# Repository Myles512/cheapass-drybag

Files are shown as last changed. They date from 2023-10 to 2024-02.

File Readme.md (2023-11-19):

# Cheapass Filament Drybag
Store filament in and print from a zipper bag. Inspired by [churls Filament Spool Drybox and Feeder](https://github.com/churls5495/Filament_Spool_Drybox).

Cereal boxes are a great idea for filament storage, but I am cheap and have way too many opened spools of filament. In theory you can place a properly dried spool into a zipper bag and never have to open it again. It should stay dry (hopefully under 10% humidity thanks to the desiccant) until you've expended the entire spool.

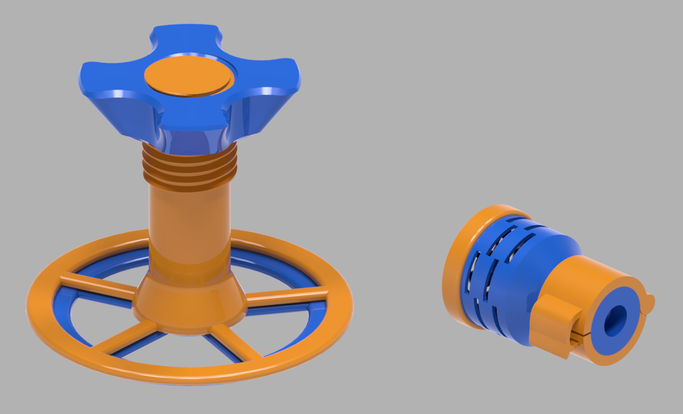
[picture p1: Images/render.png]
Render of the cheapass drybag


* Screw a [PC4-M10 bowden coupler](https://www.3dlabtech.ca/product/pneumatic-bowden-coupler-pc4-m10/) or [PC4-M6 bowden coupler](https://www.3dlabtech.ca/product/pneumatic-bowden-coupler-pc4-m6/) into the top of the guide.
* Insert a short length of 4mm OD ptfe tubing through the coupler and desiccant storage chamber.
* Attach turntable top and bottom with a [608 skateboard bearing](https://www.3dlabtech.ca/product/s608zz-bearing-abec-7-pack-of-10/).
* Load some desiccant or molecular sieve into the storage chamber and screw the lid on.
* Cut a small hole in the corner of a zipper bag, a little smaller than the ridged part of the guide.
* Insert the ridged side of the guide through the hole in the bag.
* Remove the built in support from the clamp and then clamp it around the bag and guide.
* Feed properly dried filament through the tube from the inside of the bag.
* Put the filament in the bag and seal it. Ensure the bag has enough air in it that the spool can spin freely.
* Place the bag on its side with the spool sitting on the turntable.
* Feed the filament into your printer and print!

Update: I've added a version with a spool guide as I found spools that have cutouts in the walls (most spools) had a tendency to catch on the desiccant chamber when a sufficient amount of filament had been used.

The bagged spools should fit fairly well into most existing filament storage (eg. reprack), and seem to sit nicely on top of enclosed printers as long as the top panel doesn't melt the bag.
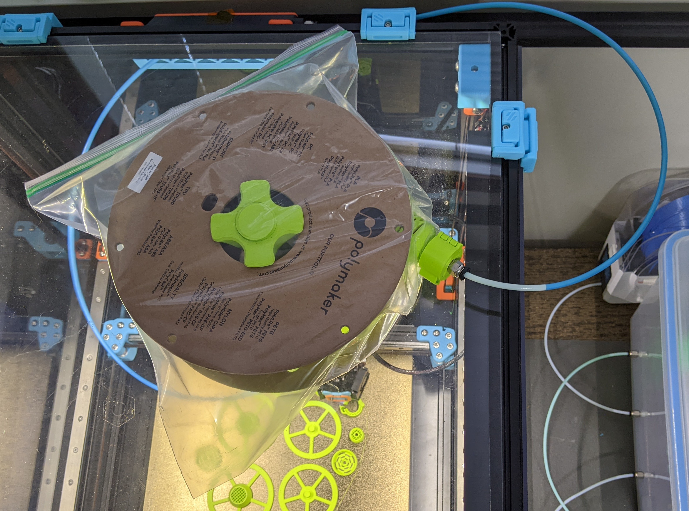
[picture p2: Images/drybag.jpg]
drybag sitting on top of a printer


If you have any comments/suggestions you can [contact me on discord](https://discord.com/users/mjlo).

gif of filament being pulled out of a drybag

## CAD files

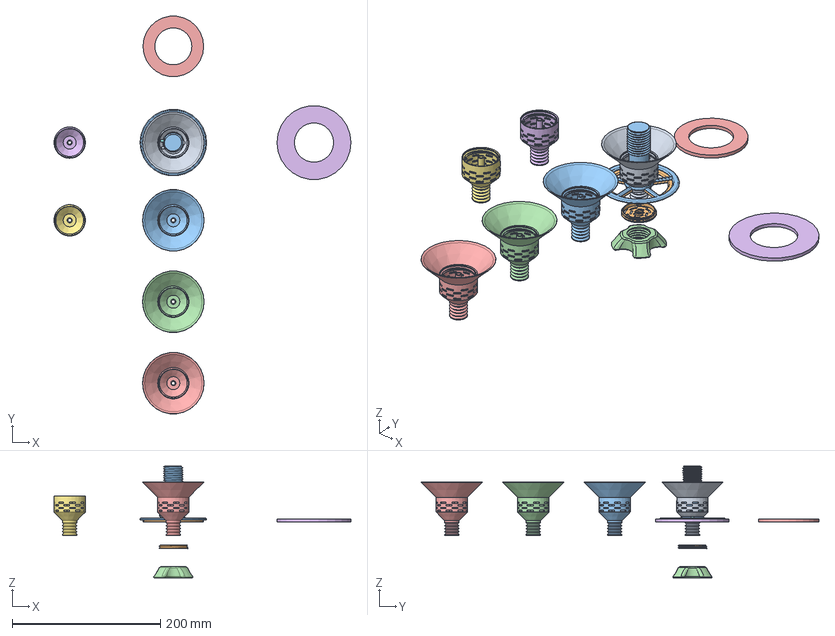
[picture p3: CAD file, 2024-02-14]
CAD/Cheapass Filament Storage Drybags.step
401.2 x 537.0 x 150.8 mm
Tube holder with desiccant storage
Bag Clamp
Turntable
Spool Big Hole Washer

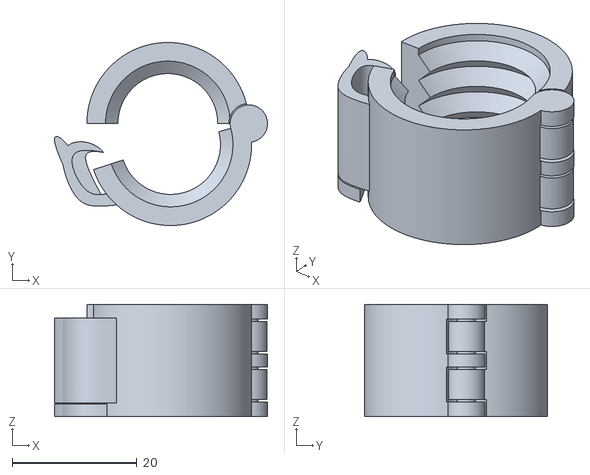
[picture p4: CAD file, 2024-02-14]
STL/Bag Clamp - Slightly Longer Tooth.stl
34.2 x 29.4 x 18.0

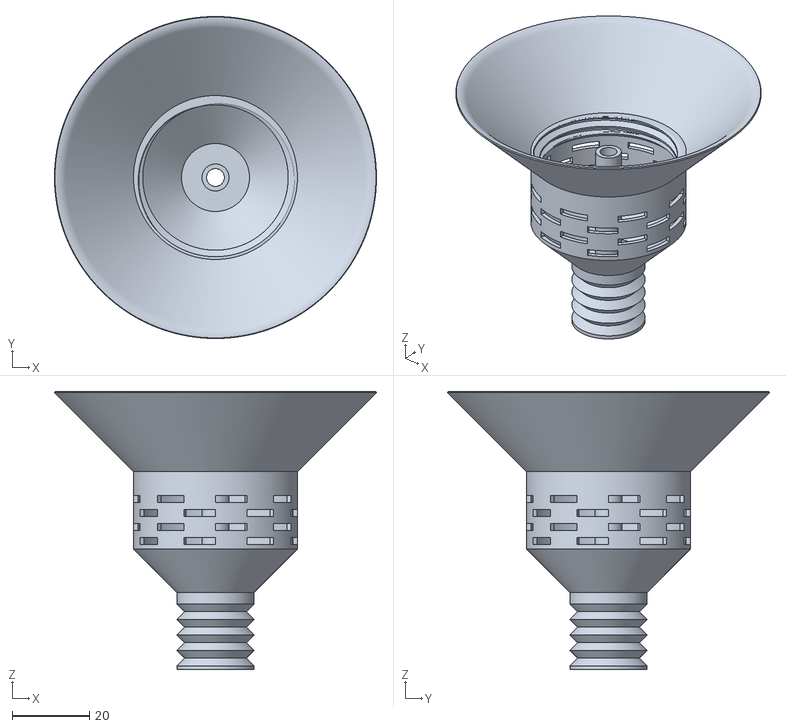
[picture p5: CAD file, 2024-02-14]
STL/Bowden Guide and Desiccant Storage with Spool Guide - Cheap Collet.stl
83.3 x 83.3 x 72.0

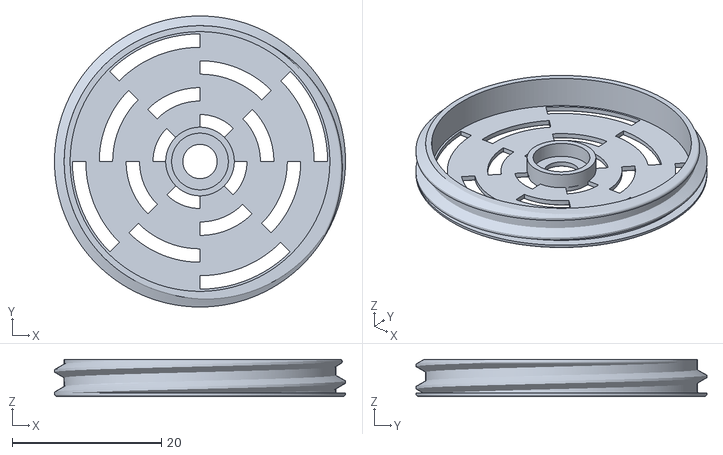
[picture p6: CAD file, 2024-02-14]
STL/Desiccant Lid.stl
39.0 x 39.0 x 5.00

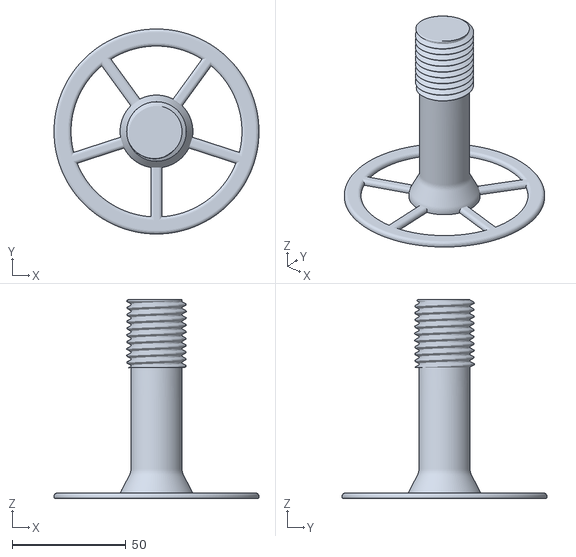
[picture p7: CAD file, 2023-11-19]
STL/Turntable 85mm.stl
90.0 x 90.0 x 87.5

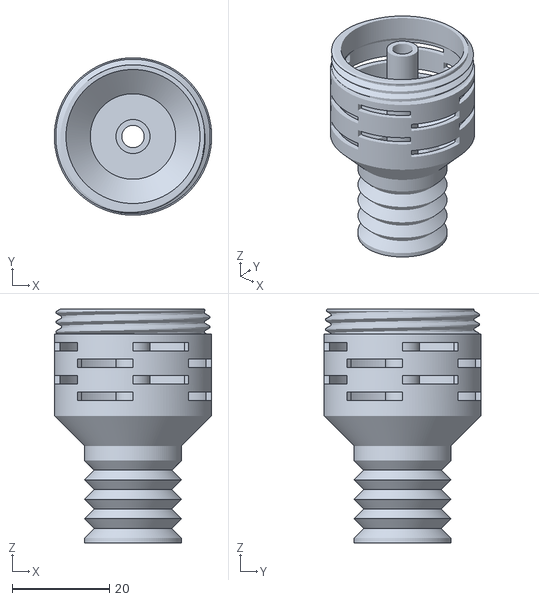
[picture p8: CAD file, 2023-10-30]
STL/Bowden Guide and Desiccant Storage - PC4-M6.stl
32.4 x 32.4 x 48.2

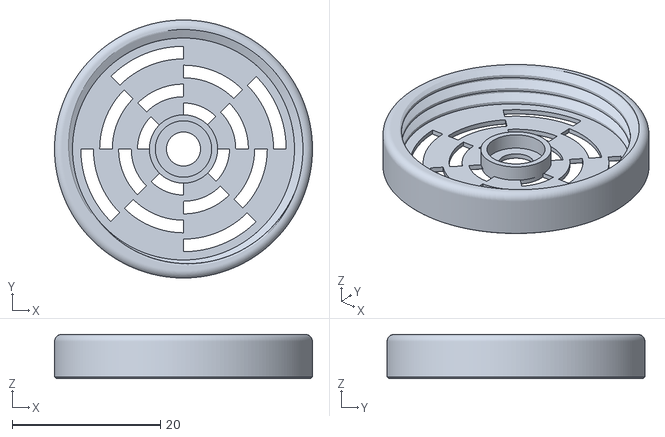
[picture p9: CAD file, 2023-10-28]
STL/Desiccant Lid - Non-Spool Guide.stl
34.8 x 34.8 x 6.00

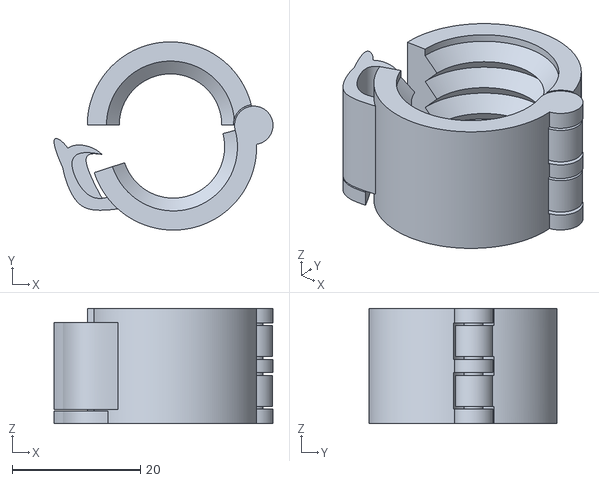
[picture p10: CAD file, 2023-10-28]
STL/Bag Clamp.stl
34.2 x 29.4 x 18.0

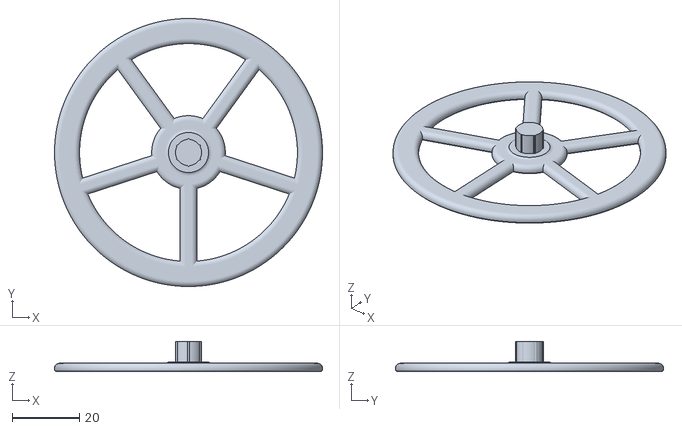
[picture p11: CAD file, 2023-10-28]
STL/Turntable Base.stl
80.0 x 80.0 x 9.00

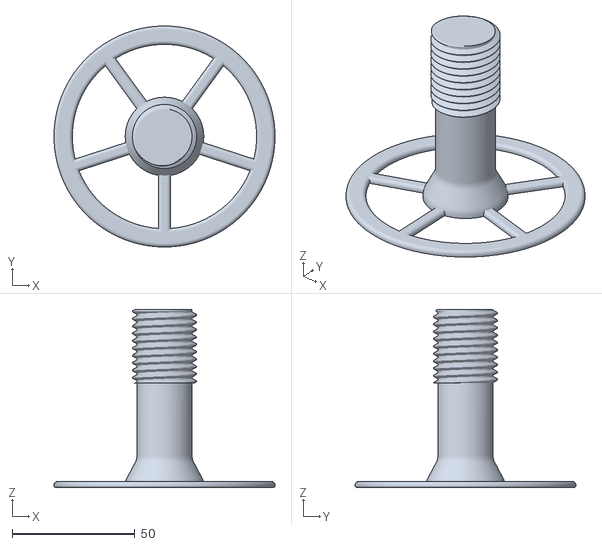
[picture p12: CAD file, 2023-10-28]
STL/Turntable.stl
90.0 x 90.0 x 72.5

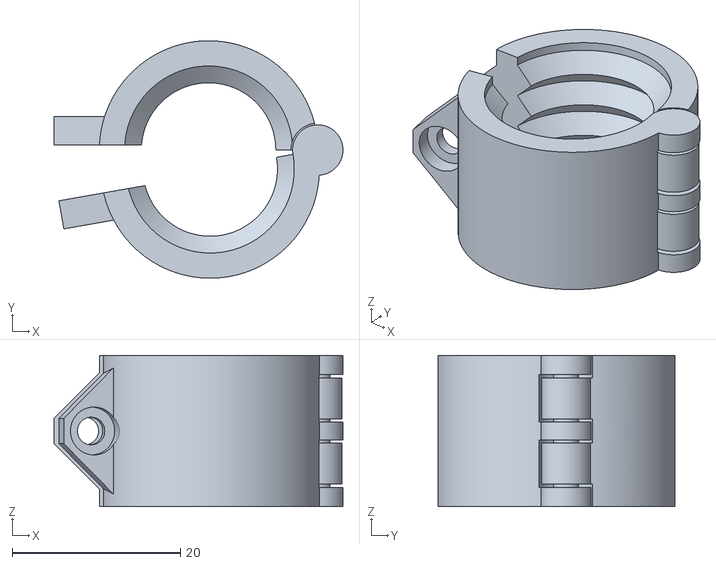
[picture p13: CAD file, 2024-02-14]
STL/Bag Clamp - Bolted.stl
34.4 x 28.3 x 18.0

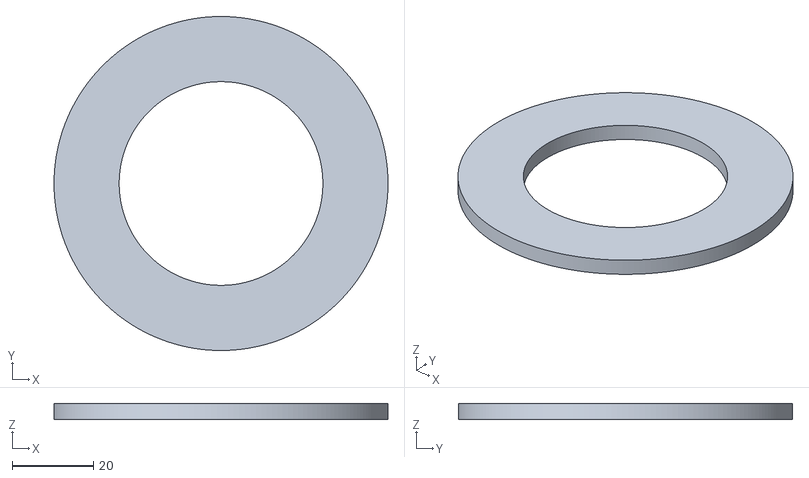
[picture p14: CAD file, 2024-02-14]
STL/Large Spool Hole Washer - 82mm.stl
82.0 x 82.0 x 4.00

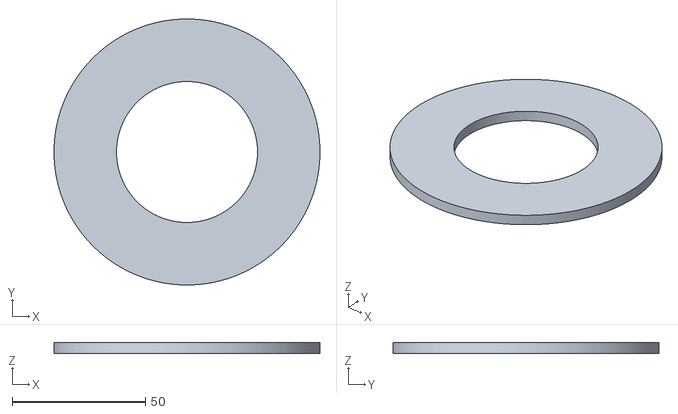
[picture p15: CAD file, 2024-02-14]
STL/Large Spool Hole Washer - 100mm.stl
100.0 x 100.0 x 4.00

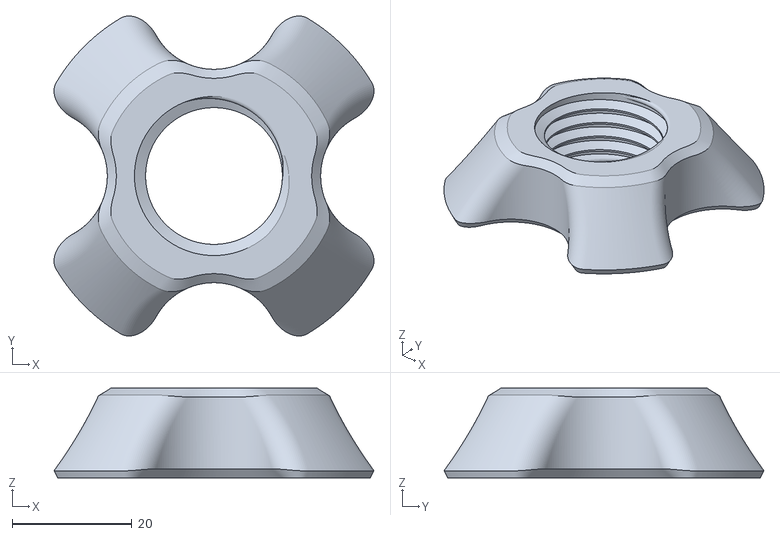
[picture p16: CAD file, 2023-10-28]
STL/Spool Nut.stl
53.4 x 53.4 x 15.0

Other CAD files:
STL/Bowden Guide and Desiccant Storage with Spool Guide - ECAS04.stl
STL/Bowden Guide and Desiccant Storage with Spool Guide - PC4-M10.stl
STL/Bowden Guide and Desiccant Storage with Spool Guide - PC4-M6.stl
STL/Bowden Guide and Desiccant Storage - PC4-M10.stl
CAD/Cheapass Filament Storage Drybags.f3d

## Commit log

2023-10-28 Version 1
    [Bag Clamp.stl, Bowden Guide and desiccant storage.stl, Cheapass Filament Storage Drybags.f3d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]
2023-10-30 Add PC4-M6
    [Bowden Guide and Desiccant Storage - PC4-M10.stl, Bowden Guide and Desiccant Storage - PC4-M6.stl, Cheapass Filament Storage Drybags.f3d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]
2023-11-19 Added longer spool turntable
    [Turntable 85mm.stl]
2023-11-19 Added spool guide version
    [Bowden Guide and Desiccant Storage with Spool Guide - PC4-M10.stl, Bowden Guide and Desiccant Storage with Spool Guide - PC4-M6.stl, Cheapass Filament Storage 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]
2024-02-14 updated spool guide
    [Bowden Guide and Desiccant Storage with Spool Guide - Cheap Collet.stl, Bowden Guide and Desiccant Storage with Spool Guide - ECAS04.stl, Bowden Guide and Desi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]
2024-02-14 Bag Clamp - Slightly Longer Tooth
    [Bag Clamp - Slightly Longer Tooth.stl]
2024-02-14 bolted clamp and washers
    [Bag Clamp - Bolted.stl, Cheapass Filament Storage Drybags.f3d, Cheapass Filament Storage Drybags.step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]
